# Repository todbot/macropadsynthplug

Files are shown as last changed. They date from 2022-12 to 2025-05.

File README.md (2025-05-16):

# MacroPadSynthPlug!

Turn MacroPad RP2040's StemmaQT port into Audio Out + MIDI In



Demo video on Youtube:
CircuitPython drum machine demo (https://www.youtube.com/watch?v=jMKC_18M17U)

## What is this?

The [Adafruit MacroPad RP2040](https://learn.adafruit.com/adafruit-macropad-rp2040/overview)
is really fun and could be a great musical instrument,
with its 12 keys, rotary encoder, OLED display, RP2040 chip, and 8MB of flash storage.

If it only had a way to get MIDI into it and Audio out of it!
Well now you can, with MacroPadSynthPlug!

MacroPadSynthPlug is a small board that plugs into a StemmaQT / Qwiic port
and gives you [TRS-A MIDI In](https://minimidi.world/) and Audio line out.
It's not I2C, but is using those pins. 

The MacroPad RP2040 can now be a stand-alone MIDI synth!

Examples provided for both [CircuitPython](https://circuitpython.org/) and [Arduino](https://arduino-pico.readthedocs.io/en/latest/):

* __drum_machine__ - CircuitPython-based drum sequencer ([demo1](https://youtu.be/jMKC_18M17U),[demo2](https://youtu.be/bJwyUjxc6VM) )
* __dronesynth__ - Arduino Mozzi 12-oscillator drone synth ([demo](https://youtu.be/kLwP-vyvtLM))
* __remixer__ - CircuitPython-based song remixer ([source](https://github.com/todbot/macropadsynthplug/tree/main/circuitpython/remixer))
* __monosynth1__ - Arduino Mozzi 2-oscillator bass monosynth w/ resonant low-pass filter ([source](https://github.com/todbot/macropadsynthplug/tree/main/arduino/monosynth1))

## How?

The [Raspberry Pi RP2040 chip](https://www.raspberrypi.com/documentation/microcontrollers/rp2040.html)
on the MacroPad RP2040 is amazingly configurable.

Normally a port like the StemmaQT I2C port would only be usable as an I2C bus. 
With the MacroPad RP2040, the two StemmaQT pins have the possible functionality:

* MacroPad RP2040 StemmaQT SDA -- GP20 - UART1 TX - PWM2B
* MacroPad RP2040 StemmaQT SCL -- GP21 - UART1 RX - PWM2A

MacroPadSynthPlug is a simple combination of two circuits:

* For MIDI in: StemmaQT SCL has an optoisolator circuit and TRS MIDI In jack

* For PWM Audio Out: StemmaQT SDA has a PWM filtering circuit and Audio Out jack

This is an "abuse" of the StemmaQT port, as it's meant only for I2C devices.
But it's safe, will not damage other StemmaQT devices,
but it does mean you "lose" the StemmaQT port for its normal use with I2C.

## Does this work for other boards with StemmaQT?

Short answer: Yes, with caveats

* For audio out, any board that can do PWM on StemmaQT SDA can use the
  Audio Out side of MacroPadSynthPlug

* For MIDI In, any boards that can do UART In on StemmaQT SCL can do TRS MIDI input. 
  A "software serial" for TRS MIDI In may work, and of course USB MIDI In will 
  always work

This makes this list of boards this works with kinda small. 

### Tested boards:

* [Adafruit MacroPad RP2040](https://learn.adafruit.com/adafruit-macropad-rp2040)

* [Adadfruit KB2040 "Keeboar"](https://learn.adafruit.com/adafruit-kb2040)

* [Adafruit QTPy RP2040](https://learn.adafruit.com/adafruit-qt-py-2040) 
  * with a PIO-based UART libary like [`SerialPIO`](https://arduino-pico.readthedocs.io/en/latest/piouart.html) or [`adafruit_pio_uart`](https://github.com/adafruit/Adafruit_CircuitPython_PIO_UART)
  * as an example, see [qtpy_mpsp_synth](./circuitpython/qtpy_mpsp_synth/code.py)

* Raspberry Pi Pico or Pico 2 
  * with a [StemmaQT](https://www.adafruit.com/product/4209) / [Qwiic](https://www.sparkfun.com/flexible-qwiic-cable-breadboard-jumper-4-pin.html) breadboard jumper cable

## Why?

Seems like fun?  I have built many little hardware synths, like:

- [PicoStepSeq](https://github.com/todbot/picostepseq)
- [picotouchsynth](https://github.com/todbot/picotouchsynth)
- [plinkykeeb](https://github.com/todbot/plinkykeeb)
- [seeknobs](https://github.com/todbot/seeknobs)

and wanted the MacroPad RP2040 to join in the fun.

## Are these for sale?

Yes! [Get one now at Tindie!](https://www.tindie.com/products/todbot/macropadsynthplug-turn-rp2040-into-a-synth/)

## Action shots

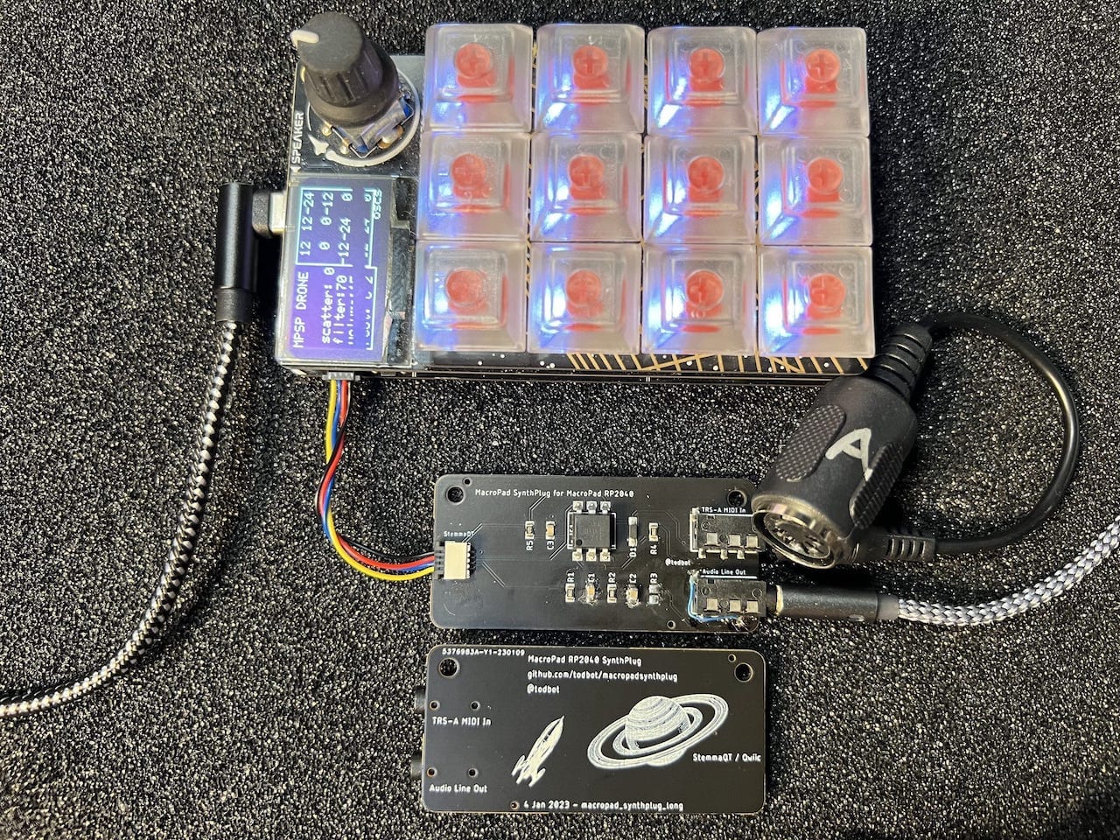
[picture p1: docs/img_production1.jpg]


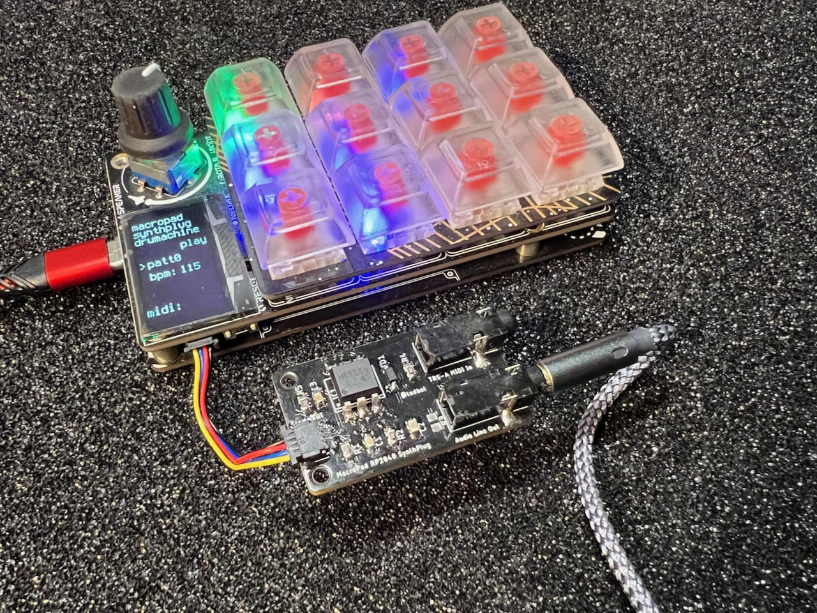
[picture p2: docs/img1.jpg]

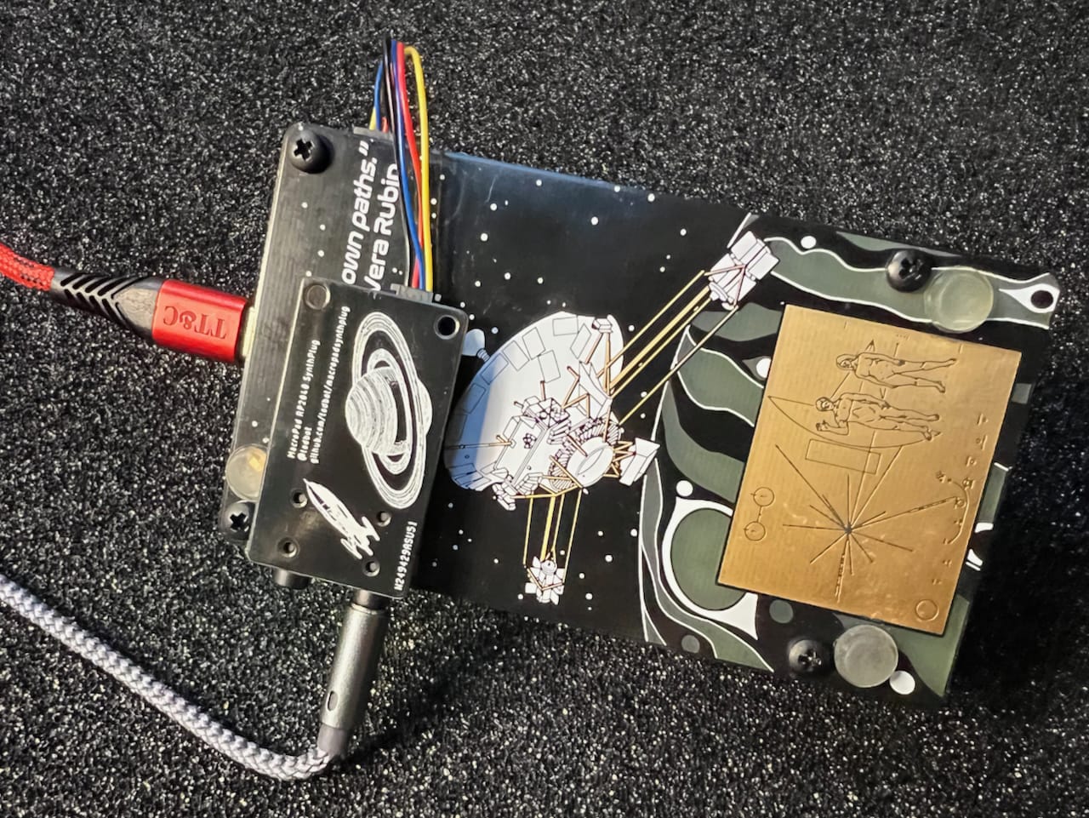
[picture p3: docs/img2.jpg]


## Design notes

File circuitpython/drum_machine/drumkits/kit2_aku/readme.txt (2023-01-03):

Samples for this kit from: https://freesound.org/people/AKUSTIKA/packs/28423/

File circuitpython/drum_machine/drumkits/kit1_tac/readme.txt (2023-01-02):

Samples mostly from: https://freesound.org/people/TicTacShutUp/packs/17/

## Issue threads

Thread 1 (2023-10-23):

MIDIserial crashes board on arduino/dronesynth

mitch-spec, 2023-10-23:
I tried to enable MIDI serial in dronesynth by adapting the commented lines. As soon as i am calling Serial1.setRX(midi_rx_pin) the board crashes and the bootloader has to be resetted. Do you have any idea whats going wrong? Thanks in advance!

```
Serial1.setRX(midi_rx_pin);
//MIDIusb.begin(MIDI_CHANNEL_OMNI);
MIDIserial.begin(MIDI_CHANNEL_OMNI);
//MIDIusb.turnThruOff();    // turn off echo
MIDIserial.turnThruOff(); // turn off echo
// USB and MIDI end
```

todbot, 2023-10-23:
Agreed I see this too.  I am suspecting something with Mozzi. I'm poking at it now but not sure what the deal is.

todbot, 2023-10-23:
This should be fixed now. Thanks for pointing this out.  I had `Serial1` instead of `Serial2`. Oops.

mitch-spec, 2023-10-24:
Thanks a lot!

Closed 2023-10-23.

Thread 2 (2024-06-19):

where is cedargrove_punkconsole

gmeader, 2024-06-19:
Where can I find cedargrove_punkconsole, that is imported in autopunkconsole/code.py

todbot, 2024-06-19:
Hi Glenn!
You can get `cedargrove_punkconsole` from the [CircuitPython Community Bundle](https://github.com/adafruit/CircuitPython_Community_Bundle), either by downloading the bundle zip and pulling the library out or by using [circup](https://learn.adafruit.com/keep-your-circuitpython-libraries-on-devices-up-to-date-with-circup/) with `circup install cedargrove_punkconsole`.  Or you can get it from [CedarGrove's repo](https://github.com/CedarGroveStudios/CircuitPython_PunkConsole).

gmeader, 2024-06-19:
Thanks. Having fun with macropadsynth plug!
I'm wondering if I can change things so that the audio out jack could be a MIDI out jack?
Can I do that just in software?
-- so I could make a program that records MIDI and plays MIDI.

todbot, 2024-09-03:
Just to clarify, the MacroPad RP2040's StemmaQT port can do MIDI in/out, but the MacroPadSynthPlug can only do MIDI in and audio out.

Closed 2024-09-03.

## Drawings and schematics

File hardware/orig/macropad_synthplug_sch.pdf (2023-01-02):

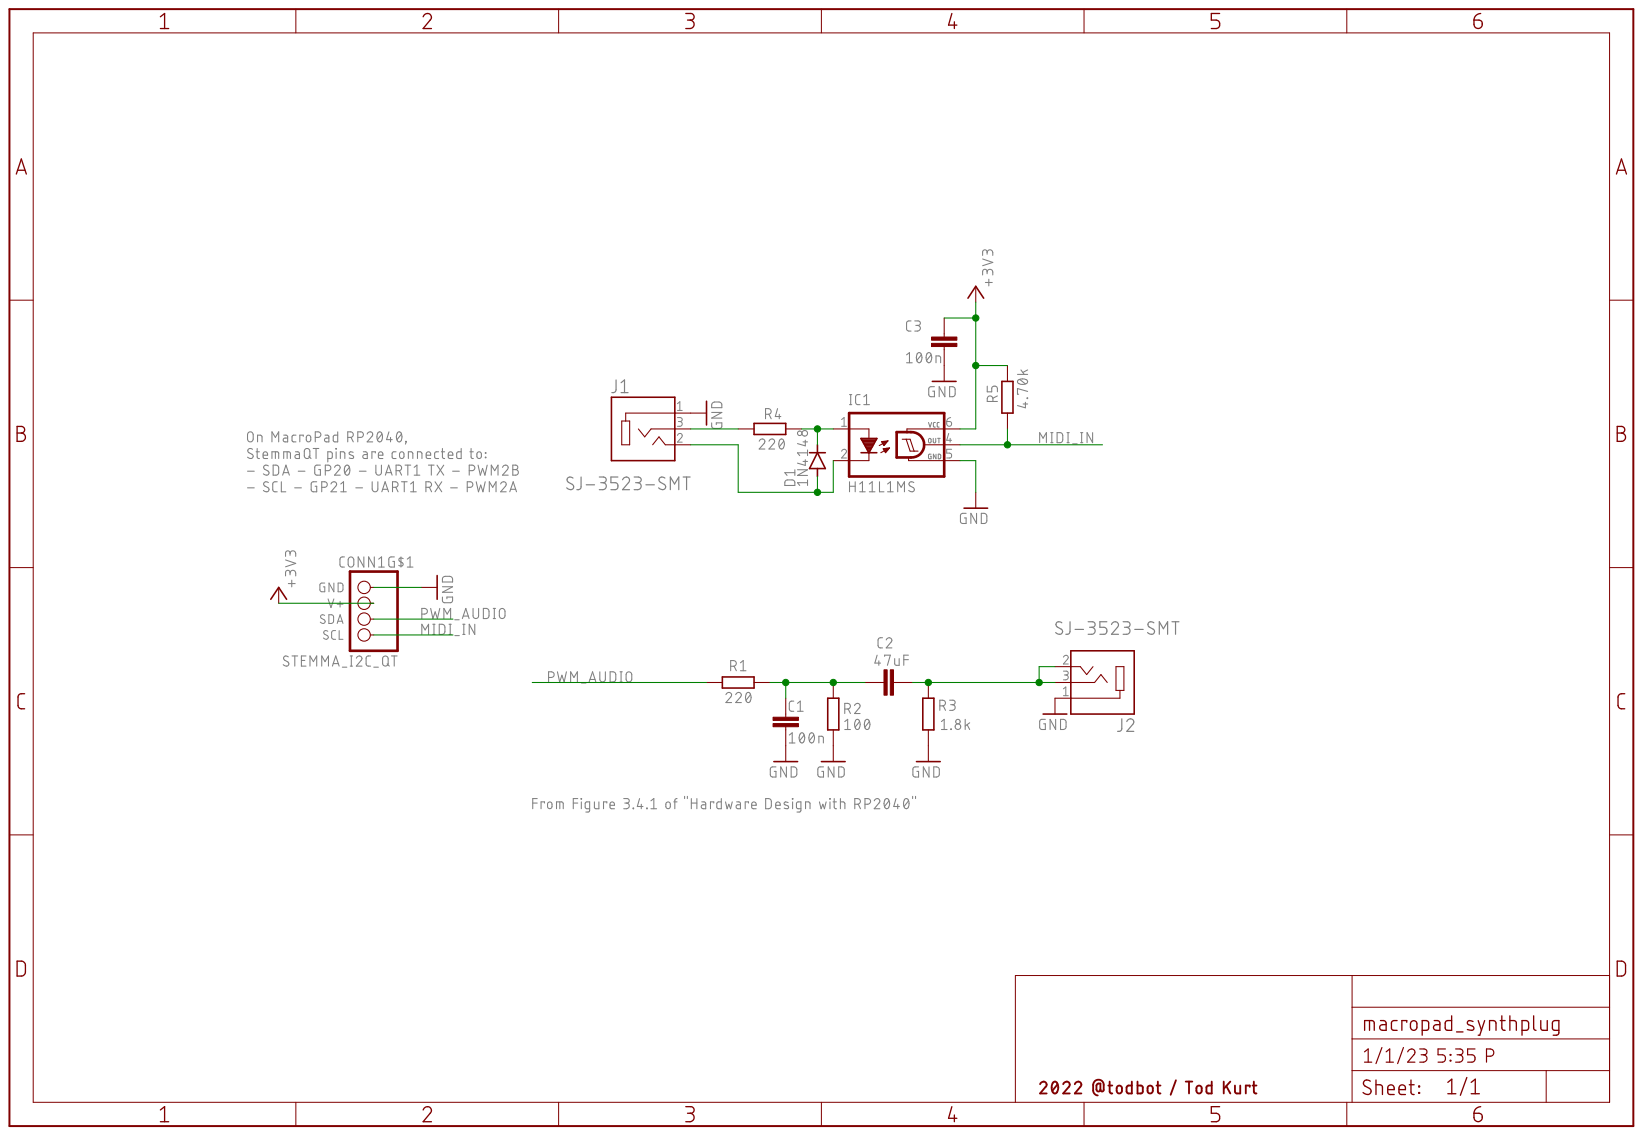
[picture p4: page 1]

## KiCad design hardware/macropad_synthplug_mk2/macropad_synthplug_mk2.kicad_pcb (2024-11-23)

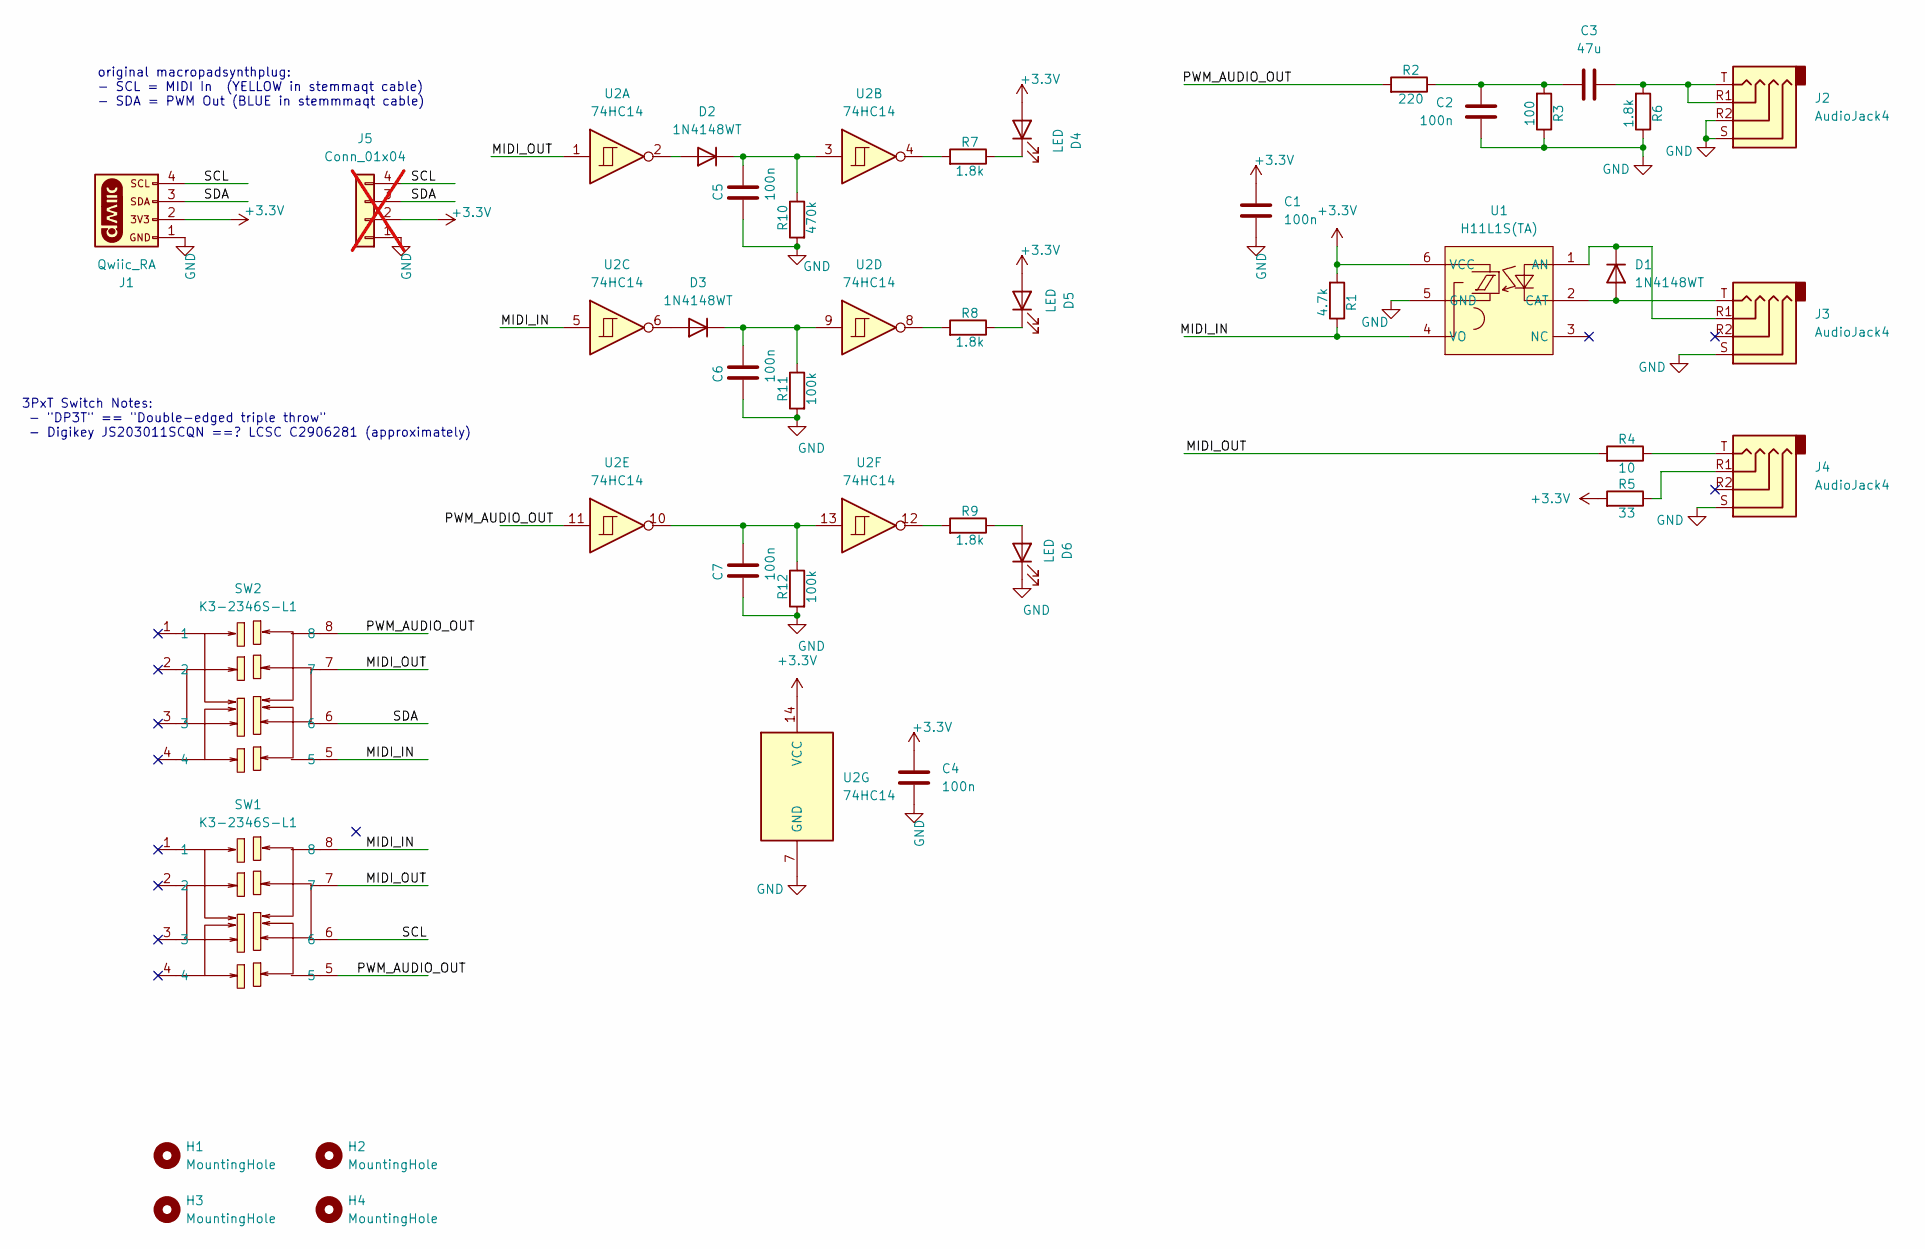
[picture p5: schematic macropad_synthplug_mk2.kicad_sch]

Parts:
C1, C2, C4, C5, C6, C7: 100n; C_0603_1608Metric
C3: 47u; C_0603_1608Metric
D1, D2, D3: 1N4148WT; D_SOD-123F; LCSC Part C64898
D4, D5, D6: LED; LED_0603_1608Metric
H1, H2, H3, H4: MountingHole; MountingHole_2.5mm
J1: Qwiic_RA; JST_SMD_1.0mm-4_RA; LCSC Part C2845363
J2, J3: AudioJack4; Jack_3.5mm_PJ320D_Horizontal; LCSC Part C431535
J4: AudioJack4; Jack_3.5mm_PJ320D_Horizontal; LCSC C431535
J5: Conn_01x04; PinHeader_1x04_P2.54mm_Vertical; not fitted
R1: 4.7k; R_0603_1608Metric
R2: 220; R_0603_1608Metric
R3: 100; R_0603_1608Metric
R4: 10; R_0603_1608Metric
R5: 33; R_0603_1608Metric
R6, R7, R8, R9: 1.8k; R_0603_1608Metric
R10: 470k; R_0603_1608Metric
R11, R12: 100k; R_0603_1608Metric
SW1, SW2: K3-2346S-L1; SW-SMD_K3-2346S-L1; LCSC Part C707355
U1: H11L1S(TA); SMD-6_L7.3-W6.5-P2.54-LS10.2-BL; LCSC Part C78589
U2: 74HC14; SOIC-14_3.9x8.7mm_P1.27mm

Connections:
+3.3V: C1.1, C4.1, D4.2 (A), D5.2 (A), J1.2, J5.2, R1.2, R5.2, U1.6 (VCC), U2.14 (VCC)
/MIDI_IN: R1.1, SW1.8, SW2.5, U1.4 (VO), U2.5
/MIDI_OUT: R4.2, SW1.7, SW2.7, U2.1
/PWM_AUDIO_OUT: R2.2, SW1.5, SW2.8, U2.11
/SCL: J1.4, J5.4, SW1.6
/SDA: J1.3, J5.3, SW2.6
GND: C1.2, C2.2, C4.2, C5.2, C6.2, C7.2, D6.1 (K), J1.1, J2.R2, J2.S, J3.S, J4.S, J5.1, R3.1, R6.1, R10.2, R11.2, R12.2, U1.5 (GND), U2.7 (GND)
unnamed: C2.1, C3.2, R2.1, R3.2
unnamed: C3.1, J2.R1, J2.T, R6.2
unnamed: C7.1, R12.1, U2.10, U2.13
unnamed: D1.2 (A), J3.T, U1.2 (CAT)
unnamed: D1.1 (K), J3.R1, U1.1 (AN)
unnamed: D2.2 (A), U2.2
unnamed: C5.1, D2.1 (K), R10.1, U2.3
unnamed: D3.2 (A), U2.6
unnamed: C6.1, D3.1 (K), R11.1, U2.9
unnamed: D4.1 (K), R7.1
unnamed: D5.1 (K), R8.1
unnamed: D6.2 (A), R9.1
unnamed: J4.R1, R5.1
unnamed: J4.T, R4.1
unnamed: R7.2, U2.4
unnamed: R8.2, U2.8
unnamed: R9.2, U2.12

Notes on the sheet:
original macropadsynthplug: - SCL = MIDI In (YELLOW in stemmaqt cable) - SDA = PWM Out (BLUE in stemmmaqt cable)
3PxT Switch Notes: - "DP3T" == "Double-edged triple throw" - Digikey JS203011SCQN ==? LCSC C2906281 (approximately)

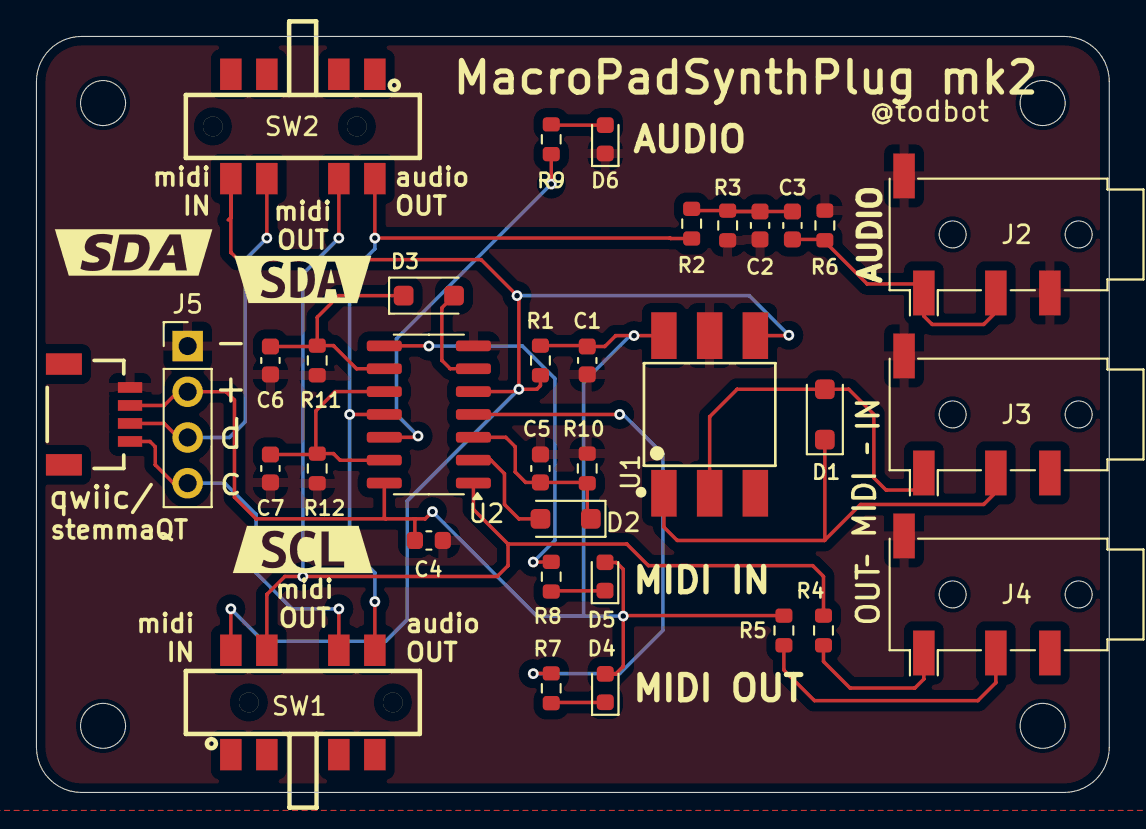
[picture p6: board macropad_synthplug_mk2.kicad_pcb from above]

Board: 2 copper layers, 59.6 x 42.0 mm, 41 parts (0 on the bottom side), 24 nets.

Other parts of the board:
kibuzzard-6721CAF2: G***; kibuzzard-6721CAF2
kibuzzard-6721CB0B: G***; kibuzzard-6721CB0B
kibuzzard-6721CC38: G***; kibuzzard-6721CC38

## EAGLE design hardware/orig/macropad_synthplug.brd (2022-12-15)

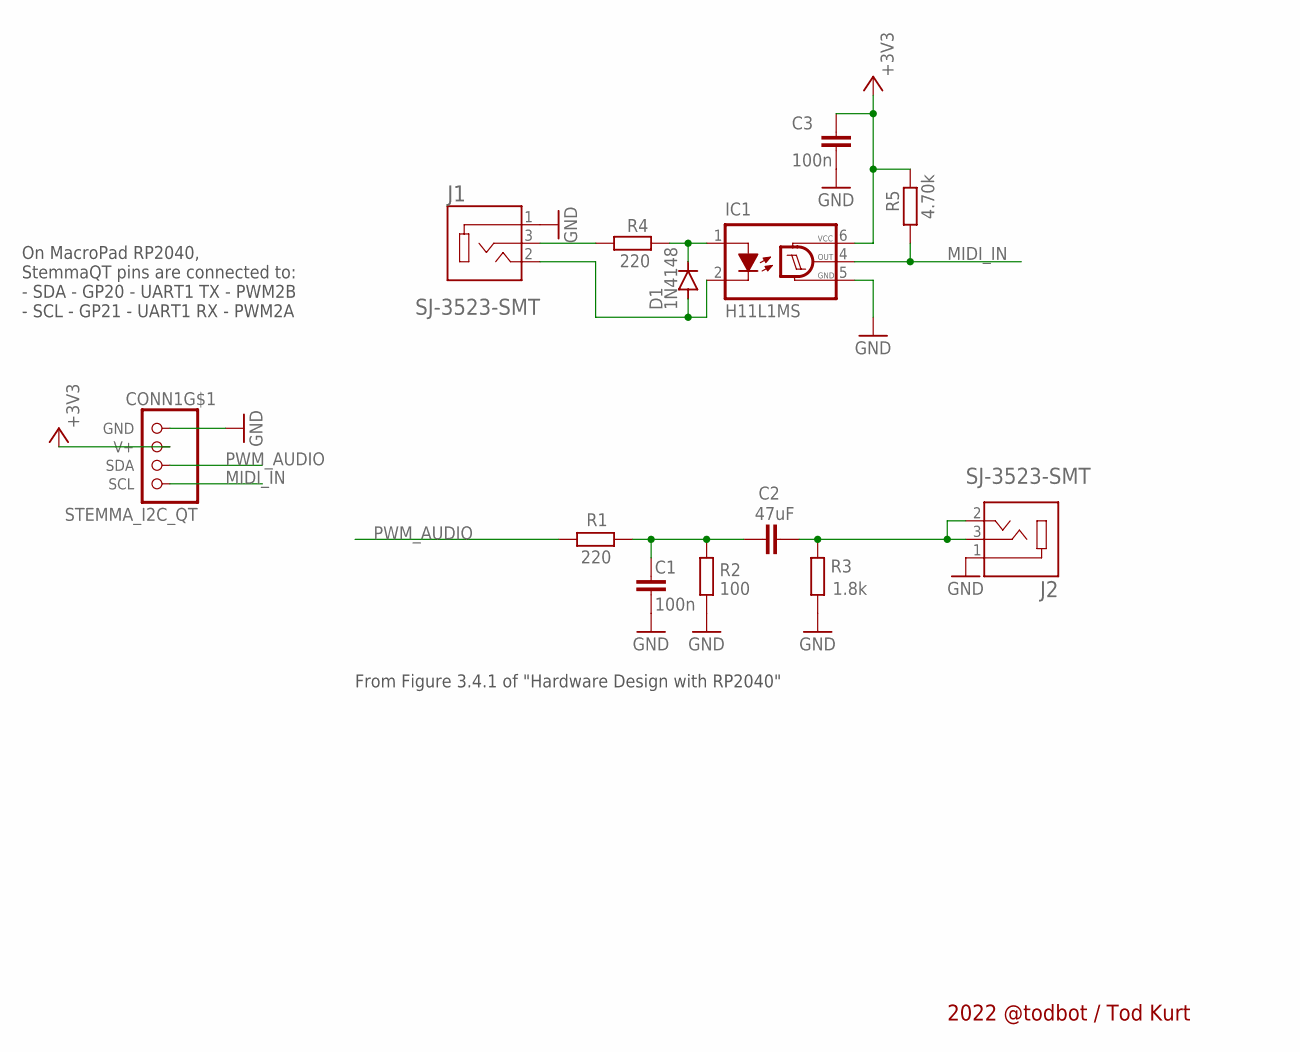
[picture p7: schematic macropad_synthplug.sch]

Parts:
C1, C3: 100n; C0805
C2: 47uF; C0805
CONN1: STEMMA_I2C_QT; JST_SH4
D1: 1N4148; SOD123
IC1: H11L1MS; DIL6-SMD
J1, J2: SJ-3523-SMT; CUI_SJ-3523-SMT
R1, R4: 220; R0805
R2: 100; R0805
R3: 1.8k; R0805
R5: 4.70k; R0805

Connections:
+3V3: C3.1, CONN1.2 (V+), IC1.6 (VCC), R5.1
GND: C1.2, C3.2, CONN1.1 (GND), IC1.5 (GND), J1.1, J2.1, R2.1, R3.2
MIDI_IN: CONN1.4 (SCL), IC1.4 (OUT), R5.2
unnamed: D1.C, IC1.1 (A), R4.1
unnamed: D1.A, IC1.2 (C), J1.2
unnamed: J1.3, R4.2
unnamed: C2.2, J2.2, J2.3, R3.1
unnamed: C1.1, C2.1, R1.1, R2.2
PWM_AUDIO: CONN1.3 (SDA), R1.2

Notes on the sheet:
On MacroPad RP2040, StemmaQT pins are connected to: - SDA - GP20 - UART1 TX - PWM2B - SCL - GP21 - UART1 RX - PWM2A
From Figure 3.4.1 of "Hardware Design with RP2040"
2022 @todbot / Tod Kurt

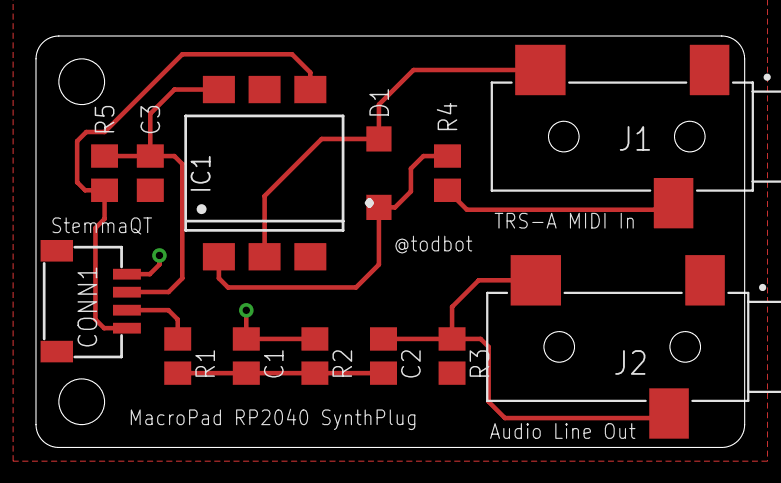
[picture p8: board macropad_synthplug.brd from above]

Board: 2 copper layers, 39.4 x 22.9 mm, 15 parts (2 on the bottom side), 9 nets.

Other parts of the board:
U$1: VINTAGE_SATURN
U$2: VINTAGE_SPACESHIP_SM1

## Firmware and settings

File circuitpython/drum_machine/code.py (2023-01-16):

# macropadsynthplug_drum_machine_code.py - drum machine on MacroPad RP2040
#
# 28 Dec 2022 - @todbot / Tod Kurt - https://github.com/todbot/macropadsynthplug
#
# Rotate macropad so keys are to the right, knob is top left
# - Key next to macropad is PLAY/STOP,
# - Then RECORD key
# - Then MUTE key
# - Then TEMPO key
# - The bottom two rows of 4 keys are the drum triggers
# - Push encoder to switch between pattern changing mode & BPM changing mode
#
#  +-------+------+------+------+------+
#  | .---. |      |      |      |      |
#  | | O | | Play | Rec  | Mute | Tap  |
#  | `---' |      |      |      |      |
#  | ----- +------+------+------+------+
#  | |   | |      |      |      |      |
#  | |   | |  4   |  5   |  6   |  7   |
#  | |   | | clap | tom  | ride | cymb |
#  | |   | +------+------+------+------+
#  | |   | |      |      |      |      |
#  | |   | |  0   |  1   |  2   |  3   |
#  | ----- | kick | snar | hatc | hato |
#  |-------+------+------+------+------+
#
#
# To install:
# - Copy this file and this whole directory to your CIRCUITPY drive
# - Install other libraries with "circup install neopixel adafruit_ticks adafruit_display_text adafruit_midi"
#
# Convert drum sounds to appropriate WAV format (mono, 22050 Hz, 16-bit signed) with command:
#  sox sound.mp3 -b 16 -c 1 -r 22050 sound.wav
#

print("macropadsynthplug drum machine start!")

import time, os, sys, json
import board, busio, keypad, rotaryio, digitalio
import rainbowio
import neopixel
import audiocore, audiomixer, audiopwmio
from adafruit_ticks import ticks_ms, ticks_diff, ticks_add
import usb_midi
#import winterbloom_smolmidi as smolmidi
import todbot_smolishmidi as smolmidi
#import adafruit_midi
#from adafruit_midi.note_on import NoteOn
#from adafruit_midi.note_off import NoteOff

from drum_display import disp_bpm, disp_play, disp_pattern, disp_kit, disp_info, disp_encmode
from drum_patterns import patterns_demo

#time.sleep(3) # wait for USB connect a bit to avoid terible audio glitches

use_macrosynthplug = True  # False to use built-in speaker of MacroPad RP2040
debug = True

patt_index = 0  # which sequence we're playing from our list of avail patterns
bpm = 120  # default BPM
steps_per_beat = 4  # divisions per beat: 8 = 32nd notes, 4 = 16th notes
num_pads = 8  # we use 8 of the 12 macropad keys as drum triggers

#
# MacroPad key layout
#

# top row of keys is special
key_PLAY = 2
key_RECORD= 5
key_MUTE = 8
key_TAP_TEMPO = 11
# the rest of keys are drum pads
keynum_to_padnum = (0, 4, -1, # pad nums go from bottom row of four: 0,1,2,3
                    1, 5, -1, # then above that, next row of four 4,5,6,7
                    2, 6, -1, # and top row are invalid pad nums (buttons used for transport)
                    3, 7, -1)

#
# Set up hardware
#

# macropadsynthplug!
midi_uart = busio.UART(rx=board.SCL, tx=None, baudrate=31250, timeout=0.001)
midi_uart_in = smolmidi.MidiIn(midi_uart) # can't do smolmidi because it wants port.readinto(buf,len)
midi_usb_in = smolmidi.MidiIn(usb_midi.ports[0]) # can't do smolmidi because it wants port.readinto(buf,len)
#midi_uart_in = adafruit_midi.MIDI( midi_in=midi_uart) # , debug=False)
#midi_usb_in = adafruit_midi.MIDI( midi_in=usb_midi.ports[0])

leds = neopixel.NeoPixel(board.NEOPIXEL, 12, brightness=0.2, auto_write=False)
leds.fill(0xff00ff); leds.show()

key_pins = (board.KEY1, board.KEY2, board.KEY3,
            board.KEY4, board.KEY5, board.KEY6,
            board.KEY7, board.KEY8, board.KEY9,
            board.KEY10, board.KEY11, board.KEY12)

keys = keypad.Keys(key_pins, value_when_pressed=False, pull=True)
encoder = rotaryio.IncrementalEncoder(board.ENCODER_B, board.ENCODER_A)  # yes, reversed
encoder_switch = keypad.Keys((board.ENCODER_SWITCH,), value_when_pressed=False, pull=True)

if use_macrosynthplug:
    audio = audiopwmio.PWMAudioOut(board.SDA) # macropadsynthplug!
else:
    audio = audiopwmio.PWMAudioOut(board.SPEAKER) # built-in tiny spkr
    speaker_en = digitalio.DigitalInOut(board.SPEAKER_ENABLE)
    speaker_en.switch_to_output(value=True)
mixer = audiomixer.Mixer(voice_count=num_pads, sample_rate=22050, channel_count=1,
                         bits_per_sample=16, samples_signed=True, buffer_size=4096)
audio.play(mixer) # attach mixer to audio playback

#
# Sequence management
#

# pattern sequence data structure looks like:
#
# patterns = [
#   { 'name': 'patt0',
#     'seq': [
#             # steps
#             #                       1 1  1 1 1 1
#             # 0 1 2 3  4 5 6 7  8 9 0 1  2 3 4 5  and so on (32)
#             [ 1,0,0,0, 1,0,0,0, 1,0,0,0, 1,0,0,0, ... ] # bd
#             [ 0,0,0,0, 1,0,0,0, 0,0,0,0, 1,0,0,0, ... ] # sd
#             ... and so on to num_pads (8)
#             ]
#     ]
#  },
# ]
#

# extend a demo pattern that has a 'base' to a full 'seq'
def make_sequence_from_demo_pattern(p):
    sq = []
    # first convert '1010' step strings to 1,0,1,0 numeric array
    for stepline_str in p['base']:
        stepline = [int(c) for c in stepline_str.replace(' ','')]
        sq.append(stepline)
    # then extend 'base' to create 'seq'
    num_copies = p['len'] // len(sq[0])
    sq * num_copies
    return sq

last_write_time = time.monotonic()
def save_patterns():
    global last_write_time
    print("saving patterns...", end='')
    #if ticks_ms() - last_write_time < 10: # only allow writes every 10 seconds, to save flash
    #    print("NO WRITE: TOO SOON")
    #    return
    last_write_time = time.monotonic()
    patts_to_sav = []
    for p in patterns:
        seq_to_sav = [''.join(str(c) for c in l) for l in p['seq']]
        patts_to_sav.append( {'name': p['name'], 'seq': seq_to_sav } )
    with open('/test_saved_patterns.json', 'w') as fp:
    #with sys.stdout as fp:
        json.dump(patts_to_sav, fp)
    print("\ndone")

def load_patterns():
    patts = []
    try:
        with open("/saved_patterns.json",'r') as fp:
            patts = json.load(fp)
            for p in patts:
                # convert str of '1010' to array 1,0,1,0, eliding whitespace, for all seq lines
                p['seq'] = [int(c) for c in s.replace(' ','') for s in p['seq']]
    except (OSError, ValueError) as error:  # maybe no file
        print("load_patterns:",error)

    if len(patts) == 0: # load demo
        print("no saved patterns, loading demo patterns")
        patts = []
        for p in patterns_demo:
            patts.append( {'name':p['name'], 'seq':  make_sequence_from_demo_pattern(p) } )

    return patts  # not strictly needed currently, but wait for it...

def copy_current_pattern():
    global patt_index, sequence
    pname = patterns[patt_index]['name']
    #seq_new = [l.copy() for l in patterns[patt_index]['seq']]  # copy list of lists
    seq_new = [l.copy() for l in sequence]  # copy list of lists
    new_patt = { 'name': 'cptst1',
                 'seq': seq_new }
    patt_index = patt_index + 1
    patterns.insert(patt_index, new_patt)
    sequence = patterns[patt_index]['seq']

def update_step_millis():
    global step_millis
    # Beat timing assumes 4/4 time signature, e.g. 4 beats per measure, 1/4 note gets the beat
    beat_time = 60 / bpm  # time length of a single beat
    beat_millis = beat_time * 1000  # time length of single beat in milliseconds
    step_millis = int(beat_millis / steps_per_beat)  # time length of a beat subdivision, e.g. 1/16th note
    # and keep "step_millis" an int so diff math is fast

#
# Drum kit management
#

# load up the drum kits' info into "kits" data struct
# keys = kit names, values = list of WAV samples
# also special key "kit_names" as order list of kit names
def find_kits():
    kit_root = '/drumkits'
    # Kits should be named/laid out like:
    # 00kick, 01snare, 02hatC, 03hatO, 04clap, 05tomL, 06ride, 07crash,
    # if there aren't 8 smamples
    kits = {}
    for kitname in sorted(os.listdir(kit_root)):
        kname = kitname.lower()
        if not kname.startswith("kit"): # ignore non-kit dirs
            continue
        kits[kname] = []  # holds all sample names of given kit
        for samplename in sorted(os.listdir(f"{kit_root}/{kname}")):
            samplename = samplename.lower()
            if samplename.endswith(".wav") and not samplename.startswith("."):
                kits[kname].append(f"{kit_root}/{kname}/{samplename}") # add it to the bag!
        if len(kits[kname]) < num_pads:
            print(f"ERROR: kit '{kname}' not enough samples! Removing...")
            del kits[kname]
    kits['kit_names'] = sorted(kits.keys())  # add special key of sorted names
    return kits

# Load wave objects upfront in attempt to reduce play latency
def load_drumkit():
    kit_name = kits['kit_names'][kit_index]
    for i in range(num_pads):
        fname = kits[kit_name][i]
        waves[i] = audiocore.WaveFile(open(fname,"rb"))  #

# play a drum sample, either by sequencer or pressing pads
def play_drum(num, pressed):
    pads_lit[num] = pressed
    voice = mixer.voice[num]   # get mixer voice
    if pressed and not pads_mute[num]:
        voice.play(waves[num],loop=False)
    else: # released
        pass   # not doing this for samples

#
# MIDI
#

# # Get midi from UART or USB
def midi_receive_smol():
    while msg := midi_uart_in.receive() or midi_usb_in.receive():  # walrus!
        if msg is not None:
            if msg.type == smolmidi.NOTE_ON:
                print("noteON:  %02d %02X" % (msg.data[0], msg.data[1]))
                play_drum( msg.data[0] % num_pads, True)
            if msg.type == smolmidi.NOTE_OFF:
                print("noteOFF: %02d %02X" % (msg.data[0], msg.data[1]))
                play_drum( msg.data[0] % num_pads, False)

# Get midi from UART or USB
def midi_receive_ada():
    while msg := midi_uart_in.receive() or midi_usb_in.receive():  # walrus!
        if msg is not None:
            #if debug: print(time.monotonic(), msg)
            if isinstance(msg, NoteOn) and msg.velocity:
                #if debug: print("noteOn:",msg.note, msg.note % num_pads)
                play_drum( msg.note % num_pads, True)
            if isinstance(msg,NoteOff) or (isinstance(msg, NoteOn) and msg.velocity==0):
                play_drum( msg.note % num_pads, False)


#
# startup
#

# load settings from disk
patterns = load_patterns()
kits = find_kits()

if debug: print("patterns",patterns)

# sequencer state
step_millis = 0 # derived from bpm, changed by "update_step_millis()" below
last_step_millis = ticks_ms()
seq_pos = 0  # where in our sequence we are
playing = False
recording = False

sequence = patterns[patt_index]['seq']  # sequence is array of [1,0,1,0]
num_steps = len(sequence[0])  # number of steps, based on length of first stepline

# drumkit state
kit_index = 0
waves = [None] * num_pads

# UI state
pads_lit = [0] * num_pads  # list of drum keys that are being played
pads_mute = [0] * num_pads # which pads are muted
pads_played = [0] * num_pads
last_led_millis = ticks_ms()  # last time we updated the LEDs
rec_held = False  # is REC button held, for deleting tracks
rec_held_used = False
mute_held = False  # is MUTE button held, for muting/unmuting tracks
tap_held = False  # is TAP/TEMPO button held
enc_sw_press_millis = 0
encoder_val_last = encoder.position
encoder_mode = 0  # 0 = change pattern, 1 = change kit, 2 = change bpm
led_min = 5  # how much to fade LEDs by
led_fade = 10 # how much to fade LEDs by

load_drumkit()
update_step_millis()

disp_bpm(bpm)
disp_play(playing,recording)
disp_pattern( patterns[patt_index]['name'] )
disp_kit( kits['kit_names'][kit_index] )
disp_encmode( encoder_mode )

print("macropadsynthplug drum machine ready!  bpm:", bpm, "step_millis:", step_millis, "steps:", num_steps)

while True:

    midi_receive_smol()
    #midi_receive_ada()

    now = ticks_ms()

    enc_sw_held = enc_sw_press_millis !=0  and (now - enc_sw_press_millis > 500)

    # LED handling
    if ticks_diff(now, last_led_millis) > 10:  # update every 10 msecs
        last_led_millis = now
        if enc_sw_held:  # edit mode
            leds[key_PLAY] = 0x44FF00
            leds[key_RECORD] = 0xFF4400
            leds[key_MUTE] = 0x0044FF
        else:
            leds[key_PLAY]   = 0x00FF00 if playing else 0x114400
            leds[key_RECORD] = 0xFF0044 if rec_held else 0xFF0000 if recording else 0x440011
            leds[key_MUTE]   = 0x001144  # mute mode button

            for i in range(num_pads):  # light up pressed drumpads
                if mute_held:  # show mute state instead
                    leds[ keynum_to_padnum.index(i) ] = 0x000000 if pads_mute[i] else 0x001144
                elif rec_held:
                    leds[ keynum_to_padnum.index(i) ] = 0xAA0022
                elif tap_held and not playing:  # light up special mode if holding taptemp button
                    leds[ keynum_to_padnum.index(i) ] = 0x111111
                if pads_lit[i]:   # also show pads being triggered, in nice JP-approved rainbows
                    leds[ keynum_to_padnum.index(i) ] = rainbowio.colorwheel( int(time.monotonic() * 20) )

        leds[:] = [[max(i-led_fade,led_min) for i in l] for l in leds] # fade released drumpads slowly
        leds.show()

    # Sequencer playing
    diff = ticks_diff( now, last_step_millis )
    if diff >= step_millis:
        late_millis = ticks_diff( diff, step_millis )  # how much are we late
        last_step_millis = ticks_add( now, -(late_millis//2) ) # attempt to make it up on next step

        # play any sounds recorded for this step
        if playing:
            for i in range(num_pads):
                if not pads_played[i]: # but play only if we didn't just play it
                    play_drum(i, sequence[i][seq_pos] ) # FIXME: what about note-off
                pads_played[i] = 0
            if(debug): print("%2d %3d " % (late_millis,seq_pos), [sequence[i][seq_pos] for i in range(num_pads)])

        # tempo indicator (leds.show() called by LED handler)
        if seq_pos % steps_per_beat == 0: leds[key_TAP_TEMPO] = 0x333333
        if seq_pos == 0: leds[key_TAP_TEMPO] = 0x3333FF # first beat indicator

        seq_pos = (seq_pos + 1) % num_steps # FIXME: let user choose?

    # Key handling
    key = keys.events.get()
    if key:
        keynum = key.key_number

        if keynum == key_PLAY:
            if key.pressed:
                if not enc_sw_held:  # normal play behavior
                    playing = not playing
                    if playing:
                        last_playing_millis = ticks_add(now, -step_millis)  # start playing!
                        seq_pos = 0
                    else:  # we are stopped
                        recording = False # so turn off recording too
                        for i in range(num_pads):
                            play_drum(i,0)
                    disp_play(playing,recording)
                else:
                    disp_info("copy patt")
                    copy_current_pattern()
                    disp_pattern( patterns[patt_index]['name'] )
                    disp_info("")

        elif keynum == key_RECORD:
            if key.pressed:
                if not enc_sw_held:  # normal record behavior
                    rec_held = True
                    rec_held_used = False
                else:
                    disp_info("save patts")
                    save_patterns()
                    disp_info("")

            if key.released and not enc_sw_held:
                rec_held = False
                if not rec_held_used:
                    recording = not recording # toggle record state
                    disp_play(playing,recording)

        elif keynum == key_MUTE:
            mute_held = key.pressed

        elif keynum == key_TAP_TEMPO:
            tap_held = key.pressed

        else: # else its a drumpad, either trigger, erase track, or mute track
            padnum = keynum_to_padnum[keynum]
            if key.pressed:
                # if REC button held while pad press, erase track
                if rec_held:
                    rec_held_used = True
                    for i in range(num_steps):
                        sequence[padnum][i] = 0
                # if MUTE button held, mute/unmute track
                elif mute_held:
                    pads_mute[padnum] = not pads_mute[padnum]
                # else trigger drum
                else:
                    play_drum( padnum, 1 )
                    if recording:
                        pads_played[padnum] = 1
                        # fix up the quantization on record
                        diff = ticks_diff( ticks_ms(), last_step_millis )
                        if debug: print("*"*30, " diff:", diff)
                        save_pos = seq_pos -1
                        if diff > step_millis//2:  #
                            save_pos += 1
                        sequence[padnum][save_pos] = 1   # save it
                    # and start recording on the beat if set to record
                    if recording and not playing:
                        playing = True
                        last_playing_millis = ticks_add(ticks_ms(), -step_millis)
                        seq_pos = 0

            if key.released:
                play_drum( padnum, 0 ) # don't strictly need this

    # Encoder hold handling
    if enc_sw_held:
        disp_info("editmode")

    # Encoder push handling
    enc_sw = encoder_switch.events.get()
    if enc_sw:
        if enc_sw.pressed:
            enc_sw_press_millis = now
        if enc_sw.released:
            if not enc_sw_held:  # press & release not press-hold
                encoder_mode = (encoder_mode + 1) % 3  # only 3 modes for encoder currently
                disp_encmode(encoder_mode)
            disp_info("")
            enc_sw_press_millis = 0


    # Encoder turn handling
    encoder_val = encoder.position
    if encoder_val != encoder_val_last:
        encoder_delta = (encoder_val - encoder_val_last)
        encoder_val_last = encoder_val
        if encoder_mode == 0:  # mode 1 == change pattern
            patt_index = (patt_index + encoder_delta) % len(patterns)
            sequence = patterns[patt_index]['seq']
            disp_pattern( patterns[patt_index]['name'] )
        elif encoder_mode == 1:  # mode 1 == change kit
            kit_index = (kit_index + encoder_delta) % len(kits['kit_names'])
            load_drumkit()
            disp_kit( kits['kit_names'][kit_index] )
        elif encoder_mode == 2:  # mode 0 == update BPM
            bpm += encoder_delta
            update_step_millis()
            disp_bpm(bpm)

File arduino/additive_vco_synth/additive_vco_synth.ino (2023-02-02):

/**
 * additive_vco by hagiwo
 * Originally from: https://note.com/solder_state/n/n30b3a8737b1e
 *
 * Mods for MacroPad RP2040 and MacroPadSynthPlug:
 * - macropad keys play notes (instead of Frequency knob)
 * - encoder turn changes Harmonics
 * - encoder push
 *
 * Must edit Mozzi library!
 * - in "Mozzi/AudioConfigRP2040.h"
 *   - change to "AUDIO_CHANNEL_1_PIN 20"
 *   - or change to "AUDIO_CHANNEL_1_PIN 16" for built-in speaker (
 *      (must also set pin 14 HIGH to enable built-in speaker)
 *
 **/
 
#include <MozziGuts.h>
#include <Oscil.h> // oscillator template
#include <tables/sin2048_int8.h> // sine table for oscillator

Oscil <SIN2048_NUM_CELLS, AUDIO_RATE> aSin1(SIN2048_DATA);
Oscil <SIN2048_NUM_CELLS, AUDIO_RATE> aSin2(SIN2048_DATA);
Oscil <SIN2048_NUM_CELLS, AUDIO_RATE> aSin3(SIN2048_DATA);
Oscil <SIN2048_NUM_CELLS, AUDIO_RATE> aSin4(SIN2048_DATA);
Oscil <SIN2048_NUM_CELLS, AUDIO_RATE> aSin5(SIN2048_DATA);
Oscil <SIN2048_NUM_CELLS, AUDIO_RATE> aSin6(SIN2048_DATA);
Oscil <SIN2048_NUM_CELLS, AUDIO_RATE> aSin7(SIN2048_DATA);
Oscil <SIN2048_NUM_CELLS, AUDIO_RATE> aSin8(SIN2048_DATA);

#define CONTROL_RATE 128 // Hz, powers of 2 are most reliable

int freq1 = 110;//base freq of OSC1
int voct = 1000;//external V/OCT LSB
int freqv1 = 440;// freq1 apply voct
int harm_knob = 0;//AD wave knob
int gain_knob = 127;
byte gain = 127;

const static float voctpow[1024] PROGMEM = {
  0,  0.004882, 0.009765, 0.014648, 0.019531, 0.024414, 0.029296, 0.034179, 0.039062, 0.043945, 0.048828, 0.05371,  0.058593, 0.063476, 0.068359, 0.073242, 0.078125, 0.083007, 0.08789,  0.092773, 0.097656, 0.102539, 0.107421, 0.112304, 0.117187, 0.12207,  0.126953, 0.131835, 0.136718, 0.141601, 0.146484, 0.151367, 0.15625,  0.161132, 0.166015, 0.170898, 0.175781, 0.180664, 0.185546, 0.190429, 0.195312, 0.200195, 0.205078, 0.20996,  0.214843, 0.219726, 0.224609, 0.229492, 0.234375, 0.239257, 0.24414,  0.249023, 0.253906, 0.258789, 0.263671, 0.268554, 0.273437, 0.27832,  0.283203, 0.288085, 0.292968, 0.297851, 0.302734, 0.307617, 0.3125, 0.317382, 0.322265, 0.327148, 0.332031, 0.336914, 0.341796, 0.346679, 0.351562, 0.356445, 0.361328, 0.36621,  0.371093, 0.375976, 0.380859, 0.385742, 0.390625, 0.395507, 0.40039,  0.405273, 0.410156, 0.415039, 0.419921, 0.424804, 0.429687, 0.43457,  0.439453, 0.444335, 0.449218, 0.454101, 0.458984, 0.463867, 0.46875,  0.473632, 0.478515, 0.483398, 0.488281, 0.493164, 0.498046, 0.502929, 0.507812, 0.512695, 0.517578, 0.52246,  0.527343, 0.532226, 0.537109, 0.541992, 0.546875, 0.551757, 0.55664,  0.561523, 0.566406, 0.571289, 0.576171, 0.581054, 0.585937, 0.59082,  0.595703, 0.600585, 0.605468, 0.610351, 0.615234, 0.620117, 0.625,  0.629882, 0.634765, 0.639648, 0.644531, 0.649414, 0.654296, 0.659179, 0.664062, 0.668945, 0.673828, 0.67871,  0.683593, 0.688476, 0.693359, 0.698242, 0.703125, 0.708007, 0.71289,  0.717773, 0.722656, 0.727539, 0.732421, 0.737304, 0.742187, 0.74707,  0.751953, 0.756835, 0.761718, 0.766601, 0.771484, 0.776367, 0.78125,  0.786132, 0.791015, 0.795898, 0.800781, 0.805664, 0.810546, 0.815429, 0.820312, 0.825195, 0.830078, 0.83496,  0.839843, 0.844726, 0.849609, 0.854492, 0.859375, 0.864257, 0.86914,  0.874023, 0.878906, 0.883789, 0.888671, 0.893554, 0.898437, 0.90332,  0.908203, 0.913085, 0.917968, 0.922851, 0.927734, 0.932617, 0.9375, 0.942382, 0.947265, 0.952148, 0.957031, 0.961914, 0.966796, 0.971679, 0.976562, 0.981445, 0.986328, 0.99121,  0.996093, 1.000976, 1.005859, 1.010742, 1.015625, 1.020507, 1.02539,  1.030273, 1.035156, 1.040039, 1.044921, 1.049804, 1.054687, 1.05957,  1.064453, 1.069335, 1.074218, 1.079101, 1.083984, 1.088867, 1.09375,  1.098632, 1.103515, 1.108398, 1.113281, 1.118164, 1.123046, 1.127929, 1.132812, 1.137695, 1.142578, 1.14746,  1.152343, 1.157226, 1.162109, 1.166992, 1.171875, 1.176757, 1.18164,  1.186523, 1.191406, 1.196289, 1.201171, 1.206054, 1.210937, 1.21582,  1.220703, 1.225585, 1.230468, 1.235351, 1.240234, 1.245117, 1.25, 1.254882, 1.259765, 1.264648, 1.269531, 1.274414, 1.279296, 1.284179, 1.289062, 1.293945, 1.298828, 1.30371,  1.308593, 1.313476, 1.318359, 1.323242, 1.328125, 1.333007, 1.33789,  1.342773, 1.347656, 1.352539, 1.357421, 1.362304, 1.367187, 1.37207,  1.376953, 1.381835, 1.386718, 1.391601, 1.396484, 1.401367, 1.40625,  1.411132, 1.416015, 1.420898, 1.425781, 1.430664, 1.435546, 1.440429, 1.445312, 1.450195, 1.455078, 1.45996,  1.464843, 1.469726, 1.474609, 1.479492, 1.484375, 1.489257, 1.49414,  1.499023, 1.503906, 1.508789, 1.513671, 1.518554, 1.523437, 1.52832,  1.533203, 1.538085, 1.542968, 1.547851, 1.552734, 1.557617, 1.5625, 1.567382, 1.572265, 1.577148, 1.582031, 1.586914, 1.591796, 1.596679, 1.601562, 1.606445, 1.611328, 1.61621,  1.621093, 1.625976, 1.630859, 1.635742, 1.640625, 1.645507, 1.65039,  1.655273, 1.660156, 1.665039, 1.669921, 1.674804, 1.679687, 1.68457,  1.689453, 1.694335, 1.699218, 1.704101, 1.708984, 1.713867, 1.71875,  1.723632, 1.728515, 1.733398, 1.738281, 1.743164, 1.748046, 1.752929, 1.757812, 1.762695, 1.767578, 1.77246,  1.777343, 1.782226, 1.787109, 1.791992, 1.796875, 1.801757, 1.80664,  1.811523, 1.816406, 1.821289, 1.826171, 1.831054, 1.835937, 1.84082,  1.845703, 1.850585, 1.855468, 1.860351, 1.865234, 1.870117, 1.875,  1.879882, 1.884765, 1.889648, 1.894531, 1.899414, 1.904296, 1.909179, 1.914062, 1.918945, 1.923828, 1.92871,  1.933593, 1.938476, 1.943359, 1.948242, 1.953125, 1.958007, 1.96289,  1.967773, 1.972656, 1.977539, 1.982421, 1.987304, 1.992187, 1.99707,  2.001953, 2.006835, 2.011718, 2.016601, 2.021484, 2.026367, 2.03125,  2.036132, 2.041015, 2.045898, 2.050781, 2.055664, 2.060546, 2.065429, 2.070312, 2.075195, 2.080078, 2.08496,  2.089843, 2.094726, 2.099609, 2.104492, 2.109375, 2.114257, 2.11914,  2.124023, 2.128906, 2.133789, 2.138671, 2.143554, 2.148437, 2.15332,  2.158203, 2.163085, 2.167968, 2.172851, 2.177734, 2.182617, 2.1875, 2.192382, 2.197265, 2.202148, 2.207031, 2.211914, 2.216796, 2.221679, 2.226562, 2.231445, 2.236328, 2.24121,  2.246093, 2.250976, 2.255859, 2.260742, 2.265625, 2.270507, 2.27539,  2.280273, 2.285156, 2.290039, 2.294921, 2.299804, 2.304687, 2.30957,  2.314453, 2.319335, 2.324218, 2.329101, 2.333984, 2.338867, 2.34375,  2.348632, 2.353515, 2.358398, 2.363281, 2.368164, 2.373046, 2.377929, 2.382812, 2.387695, 2.392578, 2.39746,  2.402343, 2.407226, 2.412109, 2.416992, 2.421875, 2.426757, 2.43164,  2.436523, 2.441406, 2.446289, 2.451171, 2.456054, 2.460937, 2.46582,  2.470703, 2.475585, 2.480468, 2.485351, 2.490234, 2.495117, 2.5,  2.504882, 2.509765, 2.514648, 2.519531, 2.524414, 2.529296, 2.534179, 2.539062, 2.543945, 2.548828, 2.55371,  2.558593, 2.563476, 2.568359, 2.573242, 2.578125, 2.583007, 2.58789,  2.592773, 2.597656, 2.602539, 2.607421, 2.612304, 2.617187, 2.62207,  2.626953, 2.631835, 2.636718, 2.641601, 2.646484, 2.651367, 2.65625,  2.661132, 2.666015, 2.670898, 2.675781, 2.680664, 2.685546, 2.690429, 2.695312, 2.700195, 2.705078, 2.70996,  2.714843, 2.719726, 2.724609, 2.729492, 2.734375,
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

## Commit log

2023-01-01 added track mutes
2023-01-01 sigh ticks overflow, why cant you be like arduino
2023-01-02 added sch pdf
    [macropad_synthplug.sch]
2023-01-02 fix pattern for multi-kit setup
    [drum_patterns.py]
2023-01-03 fix kit1_tac, prepare for save/load patterns
    [code.py]
2023-01-05 add patterns save/load first cut
2023-01-05 long version of board
    [macropad_synthplug_long.brd, macropad_synthplug_long.sch]
2023-01-08 submit long version to fab
    [macropad_synthplug_long.brd, macropad_synthplug_long.sch]
2023-01-08 cleanup arduino hardware test 1
2023-01-11 rework pattern storage, now using bit positions
    [code.py, drum_patterns.py]
2023-01-13 invert patterns data structure to make it easier to read and design demo patterns
    [code.py, drum_patterns.py]
2023-01-21 get the trrs pinout right for realsies yeesh
    [macropad_synthplug_long.brd, macropad_synthplug_long.sch]
2023-01-21 arduino tests rename
2023-01-27 monosynth1 mostly works
    [macropad_synthplug_long.sch]
2023-03-09 cleanup silkscreen, send to fab
    [macropad_synthplug_long.brd]
2023-03-19 circuitpython drum_machine: how did I miss this
2023-10-23 arduino/dronesynth, fix serial midi input, issue #1
    [dronesynth.ino, macropad_ui.h]
2023-10-23 arduino/dronesynth: handle noteon/noteoff better
2023-10-23 arduino/monosynth1: fix serial MIDI in
    [monosynth1.ino]
2024-10-22 new synthplug incoming
    [macropad_synthplug_mk2.kicad_pcb, macropad_synthplug_mk2.kicad_sch]
2024-10-22 sch reorg
    [macropad_synthplug.brd, macropad_synthplug.sch, macropad_synthplug_long.brd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]
2024-10-22 mk2 size and silkscreen update
    [macropad_synthplug_mk2.kicad_pcb, macropad_synthplug_mk2.kicad_sch]
2024-10-22 mk2 routing fixes
    [macropad_synthplug_mk2.kicad_pcb]
2024-10-30 silkscreen for mk2
    [macropad_synthplug_mk2.kicad_pcb]
2024-11-23 mk2 silkscreen update
    [macropad_synthplug_mk2.kicad_pcb]
